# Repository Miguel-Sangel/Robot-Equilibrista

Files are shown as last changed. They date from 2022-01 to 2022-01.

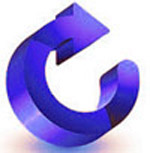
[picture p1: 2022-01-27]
src/html/GIRO-D.jpg

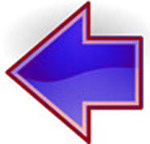
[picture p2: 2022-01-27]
html/FLECHA-I.jpg

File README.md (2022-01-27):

# Robot-Equilibrista
 
Este proyecto esta enfocado en crear un robot con una base de dos ruedas con control diferencial y que sea capaz de mantener el equilibrio.
Proyectos de este tipo se pueden desarrollar de distintas formas y de hecho se pueden encontrar unos cuantos ejemplos aquí en GitHub, pero la particularidad de este proyecto es hacerlo bajo el entorno de programación de robot ROS.

# Demostración. 
https://youtu.be/aQocPO_j5Mg 

# Descripción
Los componentes utilizados para la construcción de este robot son:

- Raspberry Pi 3
- 2 motores GA37-520 DC de 12V. Con Encoder incorporado
- Controlador para los motores TB6612FNG
- Sensor IMU MPU-6050 (acelerómetro 3 ejes y giroscopio 3 ejes)
- Bateria
- Camara USB
- Carcasa realizada en impresión 3D por el Club de Robótica de Granada.

Esquema de conexiones. (Los puertos GPIO de la Raspberry se pueden cambiar a su gusto siempre que el codigo se reajuste para que concuerde con los valores escogidos)

Esquema (Encoder antiguo)

# Instalación
Todo el proceso descrito a continuación esta orientado al sistema operativo Ubuntu Mate 18.04 LTS, que es el que admite la Raspberry  pi 3 Model B+ y el framework ROS. Para versiones posteriores tener en cuenta las indicaciones de los sitios oficiales.

Por otro lado comentar que aun pudiendo conectar un monitor, teclado y ratón a la Raspberry, lo propio es acceder a ella a través de una conexión remota vía wifi o internet. En mi caso uso TigerVNC, https://tigervnc.org/, aunque existen otras aplicaciones y por lo tanto, que cada cual use la que mas le convenga.

En primer lugar instalaremos la biblioteca Pigpio para poder acceder a los puertos GPIO  de la Raspberry. Para esto seguiremos las indicaciones del sitio: https://abyz.me.uk/rpi/pigpio/download.html

Iniciaremos una terminal y ejecutaremos esta serie de instrucciones:

 - wget https://github.com/joan2937/pigpio/archive/master.zip
 - unzip master.zip
 - cd pigpio-master
 - make
 - sudo make install

Instalación del Sistema Operativo para Robot ROS. 
Teniendo en cuenta que la versión de ROS depende de la versión de Ubuntu, en nuestro caso la versión 18.04, eligiéremos ROS-Kinetic. http://wiki.ros.org/kinetic/Installation/Ubuntu

Abriendo una terminal de Ubuntu teclearemos las siguientes instrucciones:

	- sudo sh -c 'echo "deb http://packages.ros.org/ros/ubuntu $(lsb_release -sc) main" > /etc/apt/sources.list.d/ros-latest.lis
	- sudo apt install curl # if you haven't already installed curl
	- curl -s https://raw.githubusercontent.com/ros/rosdistro/master/ros.asc | sudo apt-key add -
	- sudo apt-get update
	- sudo apt-get install ros-kinetic-desktop-full
 
 	- echo "source /opt/ros/kinetic/setup.bash" >> ~/.bashrc
	- source ~/.bashrc

Con esto tendremos instalado ROS, ahora instalaremos otros paquetes que nos ampliaran las capacidades de ROS.

Rosbridge_suit, http://wiki.ros.org/rosbridge_suite, es una herramienta que nos permite conectar con el sistema ROS del robot a traves de una pagina web.

 	- sudo apt-get install ros-kinetic-rosbridge-server

Usb_cam, http://wiki.ros.org/usb_cam, paquete que permite el acceso de ROS a los datos devueltos por la Camara USB.

 	- sudo apt-get install ros-kinetic-usb-cam

Web_video_serve, http://wiki.ros.org/web_video_server, este paquete transmite temas de ROS con contenido de video para poder ser leido en una pagina web.

	- sudo apt-get install ros-kinetic-web-video-server

Ahora crearemos un espacio de trabajo para contener nuestro proyecto. Para esto crearemos una carpeta con el nombre que deseemos, por ejemplo "equilibrista" y dentro de ella una que deve llamarse "src".

	- mkdir -p ~/equilibrista/src
	- cd ~/equilibrista/src
	
En este punto descargaremos el contenido de este repositorio.

	- git clone https://github.com/Miguel-Sangel/Robot-Equilibrista
	
Ahora ya solo nos queda compilar el paquete con la herramienta que ROS dispone para la compilación de proyectos.

	- cd ..
	- catkin_make
	
Si todo va bien y no da ningun error

	- echo "source ~/equilibrista/devel/setup.bash" >> ~/.bashrc
	
Ya esta casi todo listo, solo nos falta copiar una de las carpetas que se nos han descargado, “html” y pegarla en el ordenador desde el cual queremos manejar al robot.

Ahora si que podemos empezar ya a jugar con nuestro robot equilibrista. Para ello, en el sistema de la Raspberry tenemos que abrir una terminal con permisos de “superusuario” pues la biblioteca de acceso a los puertos “pigpio” nos lo exige.

	- sudo su
	Aquí tendremos que teclear nuestra contraseña
Volveremos a obtener los entornos de configuración

	- source /opt/ros/kinetic/setup.bash
	- source ~/equilibrista/devel/setup.bash

Antes de ejecutar la aplicación, seria conveniente saber la dirección de acceso a la red de nuestro robot pues debemos modificarla en el fichero “html.html” que se encuentra en la carpeta “html” que hemos copiado al ordenador desde el cual vamos a controlar a nuestro robot.
Se puede ejecutar este comando, en la Raspberry para obtener dicha dirección.

	- ifconfig

Una vez conocida la dirección, editamos el fichero “html.html” del ordenador de control y sustituimos en la linea 20 la dirección existente por la que hemos obtenido, manteniendo el puerto :9090

Y ya si que si podemos ejecutar la aplicación

	- roslaunch equi inicio.launch

Esperamos a que termine de iniciar y nos vamos al ordenador de control y desde dentro de la carpeta html  ejecutamos o pinchamos dos veces sobre el fichero html.html para que lo abra el navegador.

Una vez que accedemos se debe ver en la parte izquierda la imagen enviadas de la cámara y a la derecha controles de avanzar girar y stop.

El botón STOP también tiene programada la función de activar el robot la primera vez que lo pulsamos, o si el robot cae para activarlo nuevamente.

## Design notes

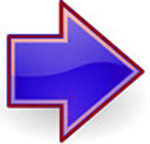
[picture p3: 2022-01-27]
html/FLECHA-D.jpg

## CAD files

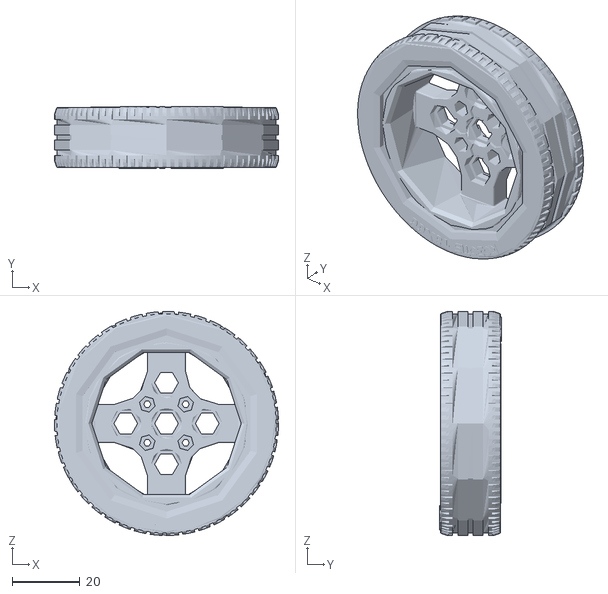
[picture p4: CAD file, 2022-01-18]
src/description/meshes/wheels/right_tire.stl
66.0 x 18.2 x 66.0

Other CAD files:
src/description/meshes/wheels/left_tire.stl

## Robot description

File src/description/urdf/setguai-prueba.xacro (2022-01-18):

<?xml version="1.0" ?>
<robot name="SetGuai" xmlns:xacro="http://ros.org/wiki/xacro">
  <!--xacro:include filename="$(find description)/urdf/common_properties.xacro"/-->
  <xacro:include filename="$(find description)/urdf/setguai.gazebo.xacro"/>
  <xacro:include filename="$(find description)/urdf/setguai_transmision.xacro"/>
  
  <xacro:property name="masa1" value="1" />
  <xacro:property name="masa2" value="2" />

  <link name="base_footprint"/>

  <joint name="base_joint" type="fixed">
    <parent link="base_footprint"/>
    <child link="base_link"/>
    <origin xyz="0.0 0.0 0.033" rpy="0 0 0"/> <!-- altura de radio -->
  </joint>

  <link name="base_link">
    <visual>  <!-- BASE -->
      <origin xyz="0.0 0.0 0.0" rpy="0 0 0"/>
      <geometry>
        <box size="0.02 0.14 0.01"/>
      </geometry>
      <material name="light_black"/>
    </visual>

    <collision>  <!-- BASE -->
      <origin xyz="0.0 0.0 0.0" rpy="0 0 0"/>
      <geometry>
        <box size="0.02 0.14 0.01"/>
      </geometry>
    </collision>

    <inertial>
      <origin xyz="0.0 0.0 0.0" rpy="0 0 0"/>
      <mass value= "${masa1}"/>
      <inertia ixx="${masa1 / 12.0 * ((0.14 * 0.14) + (0.01 * 0.01))}" ixy="0" ixz="0" iyy="${masa1 / 12.0 * ((0.02 * 0.02) + (0.01 * 0.01))}" iyz="0" izz="${masa1 / 12.0 * ((0.14 * 0.14) + (0.02 * 0.02))}" />
    </inertial>
  </link>

  <joint name="wheel_left_joint" type="continuous">
    <parent link="base_link"/>
    <child link="wheel_left_link"/>
    <origin xyz="0.0 0.08 0.00" rpy="-1.57 0 0"/>
    <axis xyz="0 0 1"/>
  </joint>

  <link name="wheel_left_link">
    <visual>
      <origin xyz="0 0 0" rpy="0 0 0"/>
      <geometry>
        <box size="0.066 0.066 0.015"/>
      </geometry>
      <material name="dark"/>
    </visual>

    <collision>
      <origin xyz="0 0 0" rpy="0 0 0"/>
      <geometry>
        <box size="0.066 0.066 0.015"/>
      </geometry>
    </collision>

    <inertial>
      <origin xyz="0 0 0" />
      <mass value="50" />
      <inertia ixx="0.001" ixy="0" ixz="0" iyy="0.001" iyz="0" izz="0.002" />
      </inertial>
  </link>

  <joint name="wheel_right_joint" type="continuous">
    <parent link="base_link"/>
    <child link="wheel_right_link"/>
    <origin xyz="0.0 -0.080 0.00" rpy="-1.57 0 0"/>
    <axis xyz="0 0 1"/>
  </joint>

  <link name="wheel_right_link">
    <visual>
      <origin xyz="0 0 0" rpy="0 0 0"/>
      <geometry>
        <box size="0.066 0.066 0.015"/>
      </geometry>
      <material name="dark"/>
    </visual>

    <collision>
      <origin xyz="0 0 0" rpy="0 0 0"/>
      <geometry>
        <box size="0.066 0.066 0.015"/>
      </geometry>
    </collision>

    <inertial>
      <origin xyz="0 0 0" />
      <mass value="50" />
      <inertia ixx="0.001" ixy="0" ixz="0" iyy="0.001" iyz="0" izz="0.002" />
      </inertial>
  </link>

  <joint name="pendulo_joint" type="fixed">
    <parent link="base_link"/>
    <child link="pendulo_link"/>
    <origin xyz="0.0 0.0 0.105" rpy="0 0 0"/>
  </joint>

  <link name="pendulo_link">
    <visual>
      <origin xyz="0.0 0.0 0.0" rpy="0 0 0"/>
      <geometry>
        <box size="0.01 0.02 0.2"/>
      </geometry>
      <material name="blue"/>
    </visual>
    <collision>
      <origin xyz="0.0 0.0 0.0" rpy="0 0 0"/>
      <geometry>
        <box size="0.01 0.02 0.2"/>
      </geometry>
    </collision>

    <inertial>
      <origin xyz="0 0 0" />
      <mass value="${masa2}" />
      <inertia ixx="${masa2 / 12.0 * ((0.02 * 0.02) + (0.2 * 0.2))}" ixy="0" ixz="0" iyy="${masa2 / 12.0 * ((0.01 * 0.01) + (0.2 * 0.2))}" iyz="0" izz="${masa2 / 12.0 * ((0.02 * 0.02) + (0.01 * 0.01))}" />
    </inertial>
  </link>

  <joint name="imu_joint" type="fixed">
    <parent link="base_link"/>
    <child link="imu_link"/>
    <origin xyz="0.0 0.0 0.195" rpy="0 0 0"/>
  </joint>

  <link name="imu_link">
      <visual name="visual">
        <origin xyz="0.01 0.0 0.0" rpy="0 0 0"/> 
        <geometry>
          <box size="0.01 0.01 0.01"/>
        </geometry>
        <material name="blue"/>
      </visual>
      <collision name="collision">
        <origin xyz="0.01 0.0 0.0" rpy="0 0 0"/> 
        <geometry>
          <box size="0.01 0.01 0.01"/>
        </geometry>
      </collision>
      <inertial>
        <inertia ixx="0.1" ixy="0" ixz="0" iyy="0.1" iyz="0" izz="0.1" />
        <mass value="1" />
      </inertial>
 </link>


</robot>

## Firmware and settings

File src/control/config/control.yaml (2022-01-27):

SetGuai:
  # Publish all joint states -----------------------------------
  joint_state_controller:
    type: joint_state_controller/JointStateController
    publish_rate: 50  
  
  # Position Controllers ---------------------------------------
  joint1_position_controller:
    type: effort_controllers/JointPositionController
    joint: joint1
    pid: {p: 100.0, i: 0.01, d: 100.0}
  

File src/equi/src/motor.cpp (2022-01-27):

#include "ros/ros.h"
//#include <wiringPi.h>
//#include <softPwm.h>
#include <pigpio.h>
#include "KalmanFilter.h"
#include "geometry_msgs/Twist.h"

//----------VARIABLES MOTOR ----------------------------
#define velocidad_izquierdo 25
#define velocidad_derecho 19
#define Adelante_izquierdo 23
#define Atras_izquierdo 24
#define Adelante_derecho 27
#define Atras_derecho 5
#define stby 21
int velocidad_deseada = 0, angulo_giro = 0;
float angle_zero = -6.5;

bool stop = true;

void leer_velocidad_deseada(const geometry_msgs::TwistPtr velocidad)
{
    angle_zero = velocidad->linear.x;
    angulo_giro = velocidad->angular.z;
    if (angle_zero > 999) { stop = false; 
                            angle_zero = -6.5;
                            ROS_WARN("Ehhhhh Quieto");
                          }
}
//------------------------------------------------------

//----------VARIABLES Y FUNCIONES ENCODER ---------------
#define sentido_izquierdo 12
#define sentido_derecho 13

#define paso_izquierdo 16
#define paso_derecho 18
// relacion ejes 45:1, diametro 0.65,- Longitud = 0.065 * 3.14 = 0.204198
// longitud por vuelta motor = 0.204198 / 45 = 0.004537
// longitud por paso = 0.004537 / 11 = 0.000412455
// #define long_paso_motor 0.000412455

int suma_paso_izdo = 0, suma_paso_dcho = 0;
int sent_izdo = 0, sent_dcho = 0;

float vel_actual_dcho = 0, vel_actual_izdo = 0;


void func_pasos_izdo(int gpio, int nivel, uint32_t tiempo)
{   if (nivel == RISING_EDGE) {        
        if (sent_izdo == 0)
            suma_paso_izdo -= 1;
        else if (sent_izdo == 1)
            suma_paso_izdo += 1;
        //ROS_WARN("suma_paso_IZDO : %d", suma_paso_dcho);
       }
}

void func_pasos_dcho(int gpio, int nivel, uint32_t tiempo)
{   if (nivel == RISING_EDGE) {
        if (sent_dcho == 0)
            suma_paso_dcho += 1;
        else if (sent_dcho == 1)
            suma_paso_dcho -= 1;
       //ROS_WARN("suma_paso_DRCHO : %d", suma_paso_dcho);
       }
}

void func_sentido_izdo(int gpio, int nivel, uint32_t tiempo)
{
    if (nivel == 0) sent_izdo = 0;
    else if (nivel == 1) sent_izdo = 1;
    else sent_izdo = 2;
   // ROS_INFO("sentido : %d", cont_sent_izdo); 
}

void func_sentido_dcho(int gpio, int nivel, uint32_t tiempo)
{
    if (nivel == 0) sent_dcho = 0;
    else if (nivel == 1) sent_dcho = 1;
    else sent_dcho = 2;
    //ROS_INFO("sentido : %d", sent_dcho); 
}
//----------------------------------------------------------

//-------------------SENSOR IMU-----------------------------
#define IMU_ID 0x68 // IMU MPU6050
#define PWR_MGMT_1   0x6B
#define SMPLRT_DIV   0x19
#define CONFIG       0x1A
#define GYRO_CONFIG  0x1B
#define INT_ENABLE   0x38
#define ACCEL_XOUT_H 0x3B

int fd;

int16_t unir(short n) { return (n << 8) | (n >> 8) & 0xff; }
short lectura[7];

int16_t ax, ay, az, gx, gy, gz;
float dt = 0.005, Q_angle = 0.001, Q_gyro = 0.005, R_angle = 0.5, C_0 = 1, K1 = 0.05;

void inicia_imu(){
   fd = i2cOpen(1, IMU_ID, 0);
   i2cWriteByteData (fd, SMPLRT_DIV, 0x07);/* divisor para el calculo velocidad muestreo del sensor 8Khz / 8=(0x07) = 1Khz*/
   i2cWriteByteData (fd, PWR_MGMT_1, 0x01);/* eje X giroscopio como referencia reloj*/
   i2cWriteByteData (fd, CONFIG, 0);		/* muestreo giroscopio 8Khz */
   i2cWriteByteData (fd, GYRO_CONFIG, 0);  /* escala Gyro +/- 250 º/s */
   i2cWriteByteData (fd, INT_ENABLE, 0x01);/* Habilita interupcion datos listos */
}

void lee_imu() {
        
        i2cReadI2CBlockData(fd, ACCEL_XOUT_H, (char*)lectura, 14);
        ax = unir(lectura[0]);
        ay = unir(lectura[1]);
        az = unir(lectura[2]);
        gx = unir(lectura[4]);
        gy = unir(lectura[5]);
        gz = unir(lectura[6]);
   //ROS_WARN("imu : %f, %f, %f, %f,", ax, ay, az, gz);
}
//-----------------------------------------------------------

/////////////////////////////////////////////////////////////////////////////////////////

int main(int argc, char **argv)
{  	ros::init(argc, argv, "motor");
	ros::NodeHandle n;

    if (gpioInitialise() < 0) return 1;
    inicia_imu();
    KalmanFilter kalmanfilter;

    //---------------MOTOR-----------------------
    gpioSetMode(Adelante_izquierdo, PI_OUTPUT);
    gpioSetMode(Atras_izquierdo, PI_OUTPUT);
    gpioSetMode(Adelante_derecho, PI_OUTPUT);
    gpioSetMode(Atras_derecho, PI_OUTPUT);
    gpioSetMode(stby, PI_OUTPUT);

    gpioSetPullUpDown(Adelante_izquierdo, PI_PUD_UP);
    gpioSetPullUpDown(Atras_izquierdo, PI_PUD_UP);
    gpioSetPullUpDown(Adelante_derecho, PI_PUD_UP);
    gpioSetPullUpDown(Atras_derecho, PI_PUD_UP);
    gpioSetPullUpDown(stby, PI_PUD_UP);

    gpioSetMode(velocidad_izquierdo, PI_OUTPUT);
    gpioSetMode(velocidad_derecho, PI_OUTPUT);
    gpioPWM(velocidad_izquierdo, 0);
    gpioPWM(velocidad_derecho, 0);
    //gpioSetPWMfrequency(velocidad_izquierdo, 500);
    //gpioSetPWMfrequency(velocidad_derecho, 500);
    gpioSetPWMrange(velocidad_izquierdo, 255);
    gpioSetPWMrange(velocidad_derecho, 255);
    
    //----------------ENCODER-------------------
    gpioSetMode(sentido_izquierdo, PI_INPUT);
    gpioSetMode(sentido_derecho, PI_INPUT);
    gpioSetMode(paso_izquierdo, PI_INPUT);
    gpioSetMode(paso_derecho, PI_INPUT);

    gpioSetPullUpDown(sentido_izquierdo, PI_PUD_DOWN);
    gpioSetPullUpDown(paso_izquierdo, PI_PUD_DOWN);
    gpioSetPullUpDown(sentido_derecho, PI_PUD_DOWN);
    gpioSetPullUpDown(paso_derecho, PI_PUD_DOWN);
         //----- interupciones -----
    gpioSetAlertFunc(paso_derecho, func_pasos_dcho);
    gpioSetAlertFunc(paso_izquierdo, func_pasos_izdo);
    gpioSetAlertFunc(sentido_derecho, func_sentido_dcho);
    gpioSetAlertFunc(sentido_izquierdo, func_sentido_izdo);
    //------------------------------------------
	
    ros::Subscriber vel_sub=n.subscribe("cmd_vel_deseada", 1, &leer_velocidad_deseada);
    ros::Publisher control_pub=n.advertise<geometry_msgs::Twist>("control", 1);
    geometry_msgs::Twist control;
	
    double kp_balance = 42, kd_balance = 0.7; // p = 55, 60, 80  --- d = 0.75,  0.85,  1,  2.5,
    double kp_speed = 12, ki_speed = 0.01;  // P = 10    --- i = 0.2
    double kp_turn = 2.5, kd_turn = 0.5;
    
    double pwm_left = 0;                // ¿sentido y salida pwm?
    double pwm_right = 0;
    double speed_control_output = 0;
    double rotation_control_output = 0;
    double balance_control_output = 0;
    double speed = 0;
    double speed_filter = 0;
    double speed_filter_old = 0;
    double speed_integeral = 0;
    
    //Setting MPU6050 calibration parameters
                // ¿-4.9?  x axle angle calibration
    float angular_velocity_zero = 0.2; // - 5.0 x axle angular velocity calibration
    float angulo_actual = 0;

    ros::Time ahora, t_ultimo = ros::Time::now();
    ros::Duration t_dif_vel;
	
    stop = true;
    int contador = 0;

    while (ros::ok)
    {
      //ROS_WARN("Ang-Act : %f", angulo_actual);
      ros::spinOnce();  // obtengo velocidad_deseada y desbloquea stop
      ahora = ros::Time::now();
      if (!stop) 
      {  
         t_dif_vel = ahora - t_ultimo;
         dt = t_dif_vel.toSec();
         if (dt >= 0.005) 
            { t_ultimo = ahora;
              contador ++;
              lee_imu();
              kalmanfilter.Angle(ax, ay, az, gx, gy, gz, dt, Q_angle, Q_gyro, R_angle, C_0, K1);
              angulo_actual = kalmanfilter.angle;
     //ROS_WARN("Angulo Actual : %f,", angulo_actual);
              if (angulo_actual > 25.0 or angulo_actual < -35.0)
                 { stop = true;
                   ROS_ERROR("Joder que me caigo"); 
                   kalmanfilter.Limpiar();
                   contador = 0;
                   suma_paso_dcho = 0;
                   suma_paso_izdo = 0;
                   pwm_left = 0;                // ¿sentido y salida pwm?
                   pwm_right = 0;
                   speed_control_output = 0;
                   rotation_control_output = 0;
                   balance_control_output = 0;
                   speed = 0;
                   speed_filter = 0;
                   speed_filter_old = 0;
                   speed_integeral = 0;
                   gpioPWM(velocidad_izquierdo, pwm_left);
                   gpioPWM(velocidad_derecho, pwm_right);
                   gpioWrite(stby, 0);
                 }
                 else { gpioWrite(stby, 1);
                        balance_control_output = kp_balance * (angulo_actual - angle_zero) + kd_balance * (kalmanfilter.Gyro_y - angular_velocity_zero);
                        if (contador == 8)
                          {  contador = 0;
                             speed = (suma_paso_dcho + suma_paso_izdo) * 0.5;
                             suma_paso_dcho = 0;
                             suma_paso_izdo = 0;
                             speed_filter = speed_filter_old * 0.7 + speed * 0.3; // filtro paso bsjoo
                             speed_filter_old = speed_filter;
                             speed_integeral += speed_filter; // velocidad acumulada
                             speed_integeral += -velocidad_deseada;   // velocidad acumulada descontando la deseada
                             if ( speed_integeral < -3000) speed_integeral = -3000;
                             else if ( speed_integeral > 3000) speed_integeral = 3000;
                             speed_control_output = kp_speed * speed_filter + ki_speed * speed_integeral;
                             rotation_control_output = angulo_giro - kd_turn * kalmanfilter.Gyro_z;
                            // ROS_WARN("Angulo_actual %f - Gyro_y %f", angulo_actual, kalmanfilter.Gyro_y);
                            // ROS_ERROR("pasos %f - speed %f - integral %f - control %f", speed, speed_filter, speed_integeral, speed_control_output);
                          }
                        pwm_left = balance_control_output + speed_control_output - rotation_control_output;
                        pwm_right = balance_control_output + speed_control_output + rotation_control_output;
                       // ROS_INFO("balance %f - speed %f - pwm %f", balance_control_output, speed_control_output, pwm_left);

                        if (pwm_left < -255) pwm_left = -255;
                        else if (pwm_left > 255) pwm_left = 255;
                        if (pwm_right < -255) pwm_right = -255;
                        else if (pwm_right > 255) pwm_right = 255;
                        //ROS_WARN("Rueda Drch %f - Rueda Izda %f", pwm_right, pwm_left);
              
                        if (pwm_left < 0)
                          { gpioWrite(Adelante_izquierdo, 1);
                            gpioWrite(Atras_izquierdo, 0);
                            gpioPWM(velocidad_izquierdo, -pwm_left);
                          }
                          else { gpioWrite(Adelante_izquierdo, 0);
                                 gpioWrite(Atras_izquierdo, 1);
                                 gpioPWM(velocidad_izquierdo, pwm_left);
                               }
                        if (pwm_right < 0)
                          { gpioWrite(Adelante_derecho, 1);
                            gpioWrite(Atras_derecho, 0);
                            gpioPWM(velocidad_derecho, -pwm_right);
                          }
                          else  { gpioWrite(Adelante_derecho, 0);
                                  gpioWrite(Atras_derecho, 1);
                                  gpioPWM(velocidad_derecho, pwm_right);
                                }
                    } // else  angulo_actual > 25
                 
	   } // dt >= 0.005
	 
      } else   // stop
             {  t_ultimo = ahora;
                kalmanfilter.Limpiar();
                contador = 0;
                suma_paso_dcho = 0;
                suma_paso_izdo = 0;
                pwm_left = 0;                // ¿sentido y salida pwm?
                pwm_right = 0;
                speed_control_output = 0;
                rotation_control_output = 0;
                balance_control_output = 0;
                speed = 0;
                speed_filter = 0;
                speed_filter_old = 0;
                speed_integeral = 0;
                gpioPWM(velocidad_izquierdo, pwm_left);
                gpioPWM(velocidad_derecho, pwm_right);
                gpioWrite(stby, 0);
             }
    } // while
    gpioWrite(stby, 0);
    gpioWrite(Adelante_izquierdo, 0);
    gpioWrite(Atras_izquierdo, 0);
    gpioWrite(Adelante_derecho, 0);
    gpioWrite(Atras_derecho, 0);
    gpioPWM(velocidad_izquierdo, 0);
    gpioPWM(velocidad_derecho, 0);
    ROS_INFO("SA CABO");
    gpioTerminate();
    i2cClose(fd);
}

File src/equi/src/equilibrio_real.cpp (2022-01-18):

#include "ros/ros.h"
#include <wiringPi.h>
#include "sensor_msgs/Imu.h"
#include "geometry_msgs/Twist.h"
#include "nav_msgs/Odometry.h"

#define PIN_PWM x

float Kp = 100; //80 bien con vel-max 1
float Ki = 70; // 20 sin velocidad
float Kd = 0.9; //0.2
float Kpvel = 0.005; // bueno 0.0125
float Kivel = 0.01;
float Kdvel = 0.00;    // bueno 0.01

float angulo_actual = 0.0, angulo_error = 0.0, angulo_error_anterior = 0.0, suma_error_angulo = 0.0;
float angulo_equilibrio = 0.0, angulo_transitorio = 0.0;
float tiempo_equilibrio = 0.0, tiempo_transitorio = 0.0;
float velocidad_deseada = 0.0, velocidad_enviada = 0.0;
float velocidad_actual = 0.0, velocidad_error = 0.0, velocidad_error_anterior = 0.0, suma_velocidad_error = 0.0;
float angulo_giro=0.0;

ros::Duration t_dif;
ros::Time ahora;

void leer_imu(const sensor_msgs::ImuPtr mensaje)
{
	angulo_actual = mensaje->orientation.y;
	ahora = mensaje->header.stamp;
}
void leer_odom(const geometry_msgs::TwistPtr mensaje)
{
	velocidad_actual = mensaje->linear.x;
}
void leer_velocidad(const geometry_msgs::TwistPtr velocidad)
{
	velocidad_deseada = velocidad->linear.x;
	angulo_giro = velocidad->angular.z;
}


int main(int argc, char **argv)
{
	ros::init(argc, argv, "equilibrio");
	ros::NodeHandle n;

    wiringPiSetupGpio();
    pinMode(velocidad_izquierdo, PMW_OUTPUT);
    pinMode(Adelante_izquierdo, OUTPUT);
    pinMode(Atras_izquierdo, OUTPUT);

	ros::Subscriber imu_sub=n.subscribe("mimu", 1, &leer_imu);
	ros::Subscriber odom_sub=n.subscribe("odom", 1, &leer_odom);
	ros::Subscriber vel_sub=n.subscribe("cmd_vel_deseada", 1, &leer_velocidad);
	ros::Publisher cmd_pub=n.advertise<geometry_msgs::Twist>("cmd_vel", 1);
	ros::Publisher control_pub=n.advertise<geometry_msgs::Twist>("control", 1);
	
	geometry_msgs::Twist velocidad;
	geometry_msgs::Twist control;
	
     
	ros::Time t_ultimo = ros::Time::now();
	
	float PID_Kp;
	float PID_Kpvel;
	float PID_Ki;
	float PID_Kivel;
	float PID_Kd;
	float PID_Kdvel;
	int A=0, B=0;
	
	while (ros::ok)
	{
	  if (angulo_actual < 0.35 and angulo_actual > -0.35)
	    {
	    
	     ROS_INFO("Ang Equil.: %f", angulo_equilibrio);
	     //ROS_INFO("A-B: %d-%d", A, B);
	    
	     ros::spinOnce();
	     ahora = ros::Time::now();
	     t_dif = ahora - t_ultimo;
	     t_ultimo = ahora;
	     
		if (t_dif.toSec() >= 0.001)
		   {
		     angulo_error = angulo_equilibrio - angulo_actual;
		
		     PID_Kp = Kp * angulo_error; // Kp
		
		     suma_error_angulo = suma_error_angulo + angulo_error * t_dif.toSec();
		
		     PID_Ki = Ki * suma_error_angulo; // Ki
		     
		     PID_Kd = Kd * (angulo_error - angulo_error_anterior) / t_dif.toSec();
		     if (isnan(PID_Kd)) PID_Kd = 0;
		     
		     velocidad_enviada = - PID_Kp - PID_Ki + PID_Kd;
		     if (velocidad_enviada > 0.5) velocidad_enviada = 0.5;   // limite segun motor
		     if (velocidad_enviada < -0.5) velocidad_enviada = -0.5;
		
		     velocidad.linear.x = velocidad_enviada;
		     velocidad.linear.y = 0;
		     velocidad.angular.z = angulo_giro;
		     
		     control.linear.x = PID_Kp;
		     control.linear.y = PID_Ki;
		     control.linear.z = PID_Kd;
		     control.angular.x = PID_Kpvel;
		     control.angular.y = angulo_equilibrio * 1000;
		     control.angular.z = angulo_actual * 1000;
		     
		     cmd_pub.publish(velocidad);
		     control_pub.publish(control);
		     //ROS_INFO("Ang-Eq-Act %f:%f:%f", angulo_equilibrio, angulo_actual, tiempo_equilibrio);
		
		     angulo_error_anterior = angulo_error;
		     A += 1;
		    }
		    
		 if (t_dif.toSec() >= 0.002)
		    {
		      ros::spinOnce();
		      velocidad_error = velocidad_deseada - velocidad_actual;
		      PID_Kpvel = Kpvel * velocidad_error;
		      suma_velocidad_error = suma_velocidad_error + velocidad_error * t_dif.toSec();
		      PID_Kivel = Kivel * suma_velocidad_error;
		      
		      PID_Kdvel = Kdvel * (velocidad_error - velocidad_error_anterior) / t_dif.toSec();
		      
		      angulo_equilibrio =  PID_Kpvel + PID_Kivel + Kdvel;
		      		      
		      velocidad_error_anterior = velocidad_error;
		      B += 1;
		    }
	   }
	    else {
	           velocidad.linear.x = 0;
	           velocidad.angular.z = 0;
		   cmd_pub.publish(velocidad);
		 }
	}
}
